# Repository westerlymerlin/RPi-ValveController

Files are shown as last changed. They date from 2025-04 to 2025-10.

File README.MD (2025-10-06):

# Valve Controller

### Valve controller is a python app that can operate 24v valves and is controlled via an HTTP API

`app.py`			    Flask application that manages the API 

----------------------------------------------------

`README.pdf`		software description and details how to setup on a Raspberry Pi

Python module documentation can be found in the folder: [docs](./docs/readme.md)

Change log can be found in the file [changelog.txt](./changelog.txt)

`Valve Control Circuit.fzz`     contains the schematics and PCB layout for use in the Fritzing application https://fritzing.org/

### JSON Commands
 
`{'status', '1'}` Return the status of all valves

`{'valveN', 'open'}` Open valve N

`{'valveN', 'close'}` Close valve N

`{'closeallvalves', 1}` close all valves and pipettes   

&nbsp;   
&nbsp;    
&nbsp;  
&nbsp;   
&nbsp;   
&nbsp;   
--------------

#### Copyright (C) 2025 Gary Twinn

This program is free software: you can redistribute it and/or modify  
it under the terms of the GNU General Public License as published by  
the Free Software Foundation, either version 3 of the License, or  
(at your option) any later version.  

This program is distributed in the hope that it will be useful,  
but WITHOUT ANY WARRANTY; without even the implied warranty of  
MERCHANTABILITY or FITNESS FOR A PARTICULAR PURPOSE. See the  
GNU General Public License for more details.  

You should have received a copy of the GNU General Public License  
along with this program. If not, see <https://www.gnu.org/licenses/>.

Author:  Gary Twinn  
Repository:  [github.com/westerlymerlin](https://github)

-------------

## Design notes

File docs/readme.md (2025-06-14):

# Module Documentation

This document contains the documentation for all the modules in this project.

---

## Contents

[app](./app.md)  
Valve Controller Web Application

A Flask-based web application for monitoring and controlling valves through a REST API.
This module serves as the main entry point and is designed to be run by Gunicorn.

Features:
- Web interface for valve status monitoring
- REST API for programmatic valve control with API key authentication
- System monitoring (CPU temperature, thread listing)
- Log viewing (application logs, Gunicorn logs, system logs)

The application exposes endpoints for valve control, system status, and log viewing.

[app_control](./app_control.md)  
Settings module, reads the settings from a settings.json file. If it does not exist or a new setting
has appeared it will creat from the defaults in the initialise function.

[logmanager](./logmanager.md)  
logmanager, setus up application logging. use the **logger** property to
write to the log.

[valvecontrol](./valvecontrol.md)  
Raspberry Pi Valve Control System

This module provides a comprehensive interface for controlling and monitoring laboratory
valves via Raspberry Pi GPIO pins. It implements safety interlocks to prevent conflicting
valve states, handles system commands, and provides status monitoring capabilities.

Features:
- Individual valve control (open/close) with conflict prevention
- Batch operations (close all valves)
- System control commands (restart)
- Status reporting for monitoring
- Logging of all valve operations and errors

The module initializes GPIO pins, defines valve configurations with their relationships,
and provides functions for valve manipulation through a consistent interface.

Dependencies:
- RPi.GPIO: For hardware control of GPIO pins
- threading.Timer: For delayed execution of commands
- logmanager: For operational logging

---

-------
#### Copyright (C) 2025 Gary Twinn  

This program is free software: you can redistribute it and/or modify
it under the terms of the GNU General Public License as published by
the Free Software Foundation, either version 3 of the License, or
(at your option) any later version.

This program is distributed in the hope that it will be useful,
but WITHOUT ANY WARRANTY; without even the implied warranty of
MERCHANTABILITY or FITNESS FOR A PARTICULAR PURPOSE. See the
GNU General Public License for more details.  
  
You should have received a copy of the GNU General Public License
along with this program. If not, see <https://www.gnu.org/licenses/>.  
  
  ##### Author: Gary Twinn  
  
 -------------

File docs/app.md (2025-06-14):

# None

# app

Valve Controller Web Application

A Flask-based web application for monitoring and controlling valves through a REST API.
This module serves as the main entry point and is designed to be run by Gunicorn.

Features:
- Web interface for valve status monitoring
- REST API for programmatic valve control with API key authentication
- System monitoring (CPU temperature, thread listing)
- Log viewing (application logs, Gunicorn logs, system logs)

The application exposes endpoints for valve control, system status, and log viewing.

## subprocess

## enumerate\_threads

## Flask

## render\_template

## jsonify

## request

## logger

## httpstatus

## valvestatus

## parsecontrol

## settings

## VERSION

#### app

#### read\_log\_from\_file

```python
def read_log_from_file(file_path)
```

Reads and returns the reversed content of a log file.

This function opens the specified file in read mode with UTF-8 encoding, reads its
contents into a list of lines, reverses the order of the lines, and returns the
reversed list.

Args:
    file_path (str): The path to the file to be read.

Returns:
    list: A list of strings representing the lines of the file, in reversed order.

#### read\_cpu\_temperature

```python
def read_cpu_temperature()
```

Reads the CPU temperature from a file specified in the application settings.

This function opens the file path defined in the settings, reads the CPU
temperature data in millidegrees Celsius, converts it to degrees Celsius, and
rounds the resulting value to one decimal place before returning it.

Raises:
    FileNotFoundError: If the file path specified in the settings does not
        exist.
    IOError: If there is an error reading the file.
    ValueError: If the temperature file content cannot be converted to a float.

Returns:
    float: The CPU temperature in degrees Celsius, rounded to one decimal place.

#### threadlister

```python
def threadlister()
```

Generates a list of threads currently running in the application.

This function retrieves all active threads in the process, collecting their
names and native thread IDs, and returns the result as a list. Each thread's
information is represented as a sublist containing the thread's name and ID.

Returns:
    list: A list of sublists where each sublist contains a thread's name
        and native thread ID.

#### index

```python
@app.route('/')
def index()
```

Define a route for the root URL that renders the 'index.html' template with various
context values including CPU temperature, valve states, application version, and
running threads.

Returns
-------
flask.Response
    The HTTP response object containing the rendered HTML template.

#### api

```python
@app.route('/api', methods=['POST'])
def api()
```

Handles API POST requests to execute instructions on a specified item.

This function is a Flask route handling API calls. It checks the headers
of the request for an API key and validates it. If the key is valid, it
processes the request to execute a command on the given item via the
`parsecontrol` function. The response about the item's status is then
returned in JSON format. In case of incorrect or missing API key, or
if the request contains malformed JSON, appropriate HTTP error
responses are returned.

Raises:
    KeyError: If the required 'item' or 'command' fields are missing from
    the request JSON payload, or if the 'Api-Key' header is not
    present or malformed.

Returns:
    Response: On valid API key and request, returns the status
    of the requested command in JSON format along with a
    201 status code.
    str: Returns an error message with a 401 status code
    in cases of unauthorized access or JSON parsing errors.

#### showplogs

```python
@app.route('/pylog')
def showplogs()
```

Route definition for displaying Python logs.

This route handles the '/pylog' URL path and renders a template
that displays the Valve-Control log, including CPU temperature
and the application version.

Returns:
    flask.Response: The rendered HTML template with context data
    including logs, log title, CPU temperature, and version.

#### showgalogs

```python
@app.route('/guaccesslog')
def showgalogs()
```

Handles the display of Gunicorn access logs and CPU temperature.

This function retrieves the current CPU temperature and the Gunicorn access logs,
and then renders the `logs.html` template to display the logs alongside the CPU
temperature.

Returns:
    str: The rendered HTML content for the logs page.

#### showgelogs

```python
@app.route('/guerrorlog')
def showgelogs()
```

Provides the view for displaying the Gunicorn error logs.

This function reads the CPU temperature and Gunicorn error log content from
files and renders them in an HTML template. It serves as the backend handling
for the endpoint `/guerrorlog`.

Returns:
    str: Rendered HTML template displaying the logs and other related
    information.

#### showslogs

```python
@app.route('/syslog')
def showslogs()
```

Handles the '/syslog' route to display system log entries in reverse order along
with CPU temperature.

Creates a Flask route that retrieves the latest system logs, reverses their
order, and renders them to an HTML template. Additionally, it retrieves and
displays the CPU temperature and a version parameter.

Returns:
    str: Rendered HTML page showing system logs, CPU temperature, and a version
    identifier.

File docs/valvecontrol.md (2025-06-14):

# None

# valvecontrol

Raspberry Pi Valve Control System

This module provides a comprehensive interface for controlling and monitoring laboratory
valves via Raspberry Pi GPIO pins. It implements safety interlocks to prevent conflicting
valve states, handles system commands, and provides status monitoring capabilities.

Features:
- Individual valve control (open/close) with conflict prevention
- Batch operations (close all valves)
- System control commands (restart)
- Status reporting for monitoring
- Logging of all valve operations and errors

The module initializes GPIO pins, defines valve configurations with their relationships,
and provides functions for valve manipulation through a consistent interface.

Dependencies:
- RPi.GPIO: For hardware control of GPIO pins
- threading.Timer: For delayed execution of commands
- logmanager: For operational logging

## Timer

## os

## GPIO

## logger

#### channellist

#### valves

#### parsecontrol

```python
def parsecontrol(item, command)
```

Parses and executes control instructions for items such as valves or system commands.

This function handles control commands for items (e.g., valves) by executing
the corresponding actions (opening, closing, restarting, etc.). It utilizes specific
rules to process the commands and takes recovery measures in case of invalid inputs
or errors.

Parameters:
item : str
    Specifies the name of the control item (e.g., 'valve1', 'closeallvalves', 'restart').
command : str
    Provides the command to execute for the given item (e.g., 'open', 'close', 'pi').

Raises:
ValueError
    If the conversion of values such as valve number fails.
IndexError
    If accessing an invalid index during item processing.

#### valveopen

```python
def valveopen(valveid)
```

Opens a valve based on its unique identifier if no conflicting valve is open.

Attempts to open the valve identified by the provided valve ID. Before opening,
it checks whether the valve marked as excluded for the specified valve is already open.
If the excluded valve is open, the operation is aborted, logging a warning.
If no conflict is found, the specified valve is opened, and this action is logged.

Parameters:
    valveid (int): The unique identifier of the valve to be opened.

#### valveclose

```python
def valveclose(valveid)
```

Closes the specified valve based on its ID.

The function identifies the valve with the given ID in the list of valves,
ensures that the valve's GPIO pin is set to a low state, and logs the
operation. This action effectively closes the valve. The provided valve
ID should match an existing valve's ID within the list.

Parameters:
    valveid (int): The ID of the valve to be closed.

#### allclose

```python
def allclose()
```

Close all valves by setting the output of the specified channels to 0.

Summary:
This function outputs a signal of 0 to all channels specified in the
'channellist', effectively closing all valves. It also logs an info
message indicating the operation.

Parameters:
channellist : list
    A list of GPIO channel numbers on which the output will be set to 0.

Returns:
None

#### status

```python
def status(value)
```

Determines the status based on a given value.

This function evaluates the provided integer value and returns a corresponding
status string. Specifically, it checks whether the value equals zero to
determine if the status is 'closed'. Any other value results in a status
of 'open'.

Parameters:
value (int): The value to evaluate for determining the status.

Returns:
str: A string representing the status. Returns 'closed' if the value is
0; otherwise, returns 'open'.

#### valvestatus

```python
def valvestatus()
```

Determines the status of valves based on their GPIO input.

This function iterates through a list of valves, checks each valve's GPIO
input status, and compiles a list of dictionaries containing the valve ID
and its respective status.

Returns:
    list[dict]: A list where each dictionary contains the ID of a valve and
    its corresponding status, based on GPIO input.

#### httpstatus

```python
def httpstatus()
```

Determine and return the status of a list of valves based on their GPIO input.

This function iterates through a list of valve objects, checks each valve's GPIO
input to determine its status and then constructs a list of dictionaries containing
the valve's ID, description, and current status.

Returns:
    list[dict]: A list of dictionaries each containing the valve's `id` (int),
    `description` (str), and its current `status` (bool or other relevant type
    returned by the `status` function).

#### reboot

```python
def reboot()
```

Reboots the local machine.

This function logs a warning message indicating that the system is about to restart
and then executes a system command to initiate a reboot.

Raises:
    This function does not explicitly raise any exceptions, but it depends on the
    behavior of the underlying operating system and might fail in environments
    without sufficient permissions.

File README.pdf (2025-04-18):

# Valve and Laser Controller

Software Functional Requirements

By Gary Twinn

## Contents

Valve and Laser Controller | 1
Contents | 2
List of Figures | 3
List of Tables | 4
Overview | 5
Input Messages | 5
Output Messages | 7
Valve to GPIO assignment | 8
Driver circuits and power supply | 9
Web interface | 11
Interfaces | 12
Valve Cable Specification | 12
Laser TTL Cable specification | Error! Bookmark not defined.
Operating System Installation | 13
Operating system | 13
Software installation | 13
Run Operating System Updates | 13
Install PIP3 for Python 3.x installation | Error! Bookmark not defined.
Install Flask installation | 13
Download Valve Controller Application | Error! Bookmark not defined.
Copy the python files to the Pi | Error! Bookmark not defined.
Nginx installation | 15
Gunicorn for Python 3.x installation | 14

## List of Figures

Figure 4: Laser TTL D Plug Assignment | Error! Bookmark not defined.

## List of Tables

## Overview

The valve and laser control software consists of a python (Python Software Foundation 2023) application to control the 12 valves of the Helium line and a single channel Transistor -Transistor Logic (TTL) output to switch on/off the Laser.

Valve | Description
| 4 He pipette input
| 4 He pipette output
| 3 He pipette output
| 4 He pipette input port 1(not currently used) ion pump gas analyser gallery A laser cell getter buffer tank turbo pump

Table 1: He line valves
The computer that controls the valves is a Raspberry Pi 4B (Raspberry PI Foundation 2020), it uses a 40 way connector to break out the required 12 GPIO pins and connect to the driver boards.

Each valve is controlled by a dedicated GPIO line on the raspberry Pi computer. The valves run on 24V DC and the Pi uses a 3.3V signal, so a driver circuit is required to step up the voltage and current from the Pi.

The computer is controlled via a RESTful API listening on port 80 for a valid json message.

The software contains logic to prevent the input and output valves on a pipette opening at the same time in the case of a mistake in the commands sent to the computer. (valve 1 and valve 2), (valve 3 and valve 4)

To simplify charging and unloading of pipettes a single command was implemented to load and unload each pipette. The pipette command contains a 0.5s delay between one valve closing and one opening.

A single command was also implemented to close all valves and switch off the laser in case of an issue.

## Input Messages

Json messages in the following formats are accepted:

Open a single valve (nn):

{
"item": "valvenn",
"command": "open"
}

Close a single valve (nn): {
"item": "valvenn",
"command": "close"
}

Close all valves:
{
"item": "closeallvalves"
"command": ""}

Get Valve Status: (for all valves and laser) {
"item": "getstatus",
"command": ""
}

## Output Messages

Following any valid command, the following data is returned: (ss = open or closed, xx = on or off )
{
"status": "ss",
"valve": 1
},
{
"status": "ss",
"valve": 2
},
{
"status": "ss",
"valve": 3
},
{
"status": "ss",
"valve": 4
},
{
"status": "ss",
"valve": 5
},
{
"status": "ss",
"valve": 6
},
{
"status": "ss",
"valve": 7
},
{
"status": "ss",
"valve": 8
},
{
"status": "ss",
"valve": 10
},
{
"status": "ss",
"valve": 11
},
{
"status": "ss",
"valve": 12
},
{
"status": "ss",
"valve": 13
}
{
"laser": "0",
"status": "xx"
}

## Valve to GPIO assignment

Valve | Designation | Connector | Designation | Valve
| 3v3 | 1 | 2 | 5v
| GPIO 02 | 3 | 4 | 5v
| GPIO 03 | 5 | 6 | GND
| GPIO 04 | 7 | 8 | GPIO 14
| GND | 9 | 10 | GPIO 15
Valve 2 | GPIO 17 | 11 | 12 | GPIO 18 | Valve 5
Valve 6 | GPIO 27 | 13 | 14 | GND
Valve 10 | GPIO 22 | 15 | 16 | GPIO 23 | Valve 1
| 3v3 | 17 | 18 | GPIO 24 | Valve 8
| GPIO 10 | 19 | 20 | GND
Valve 7 | GPIO 09 | 21 | 22 | GPIO 25
Valve 11 | GPIO 11 | 23 | 24 | GPIO 08
| GND | 25 | 26 | GPIO 07
| GPIO 00 | 27 | 28 | GPIO 01
| GPIO 05 | 29 | 30 | GND
| GPIO 06 | 31 | 32 | GPIO 12 | Ready LED
Valve 3 | GPIO 13 | 33 | 34 | GND
Valve 4 | GPIO 19 | 35 | 36 | GPIO 16
Valve 13 | GPIO 26 | 37 | 38 | GPIO 20
| GND | 39 | 40 | GPIO 21 | Valve 12

Table 2: GPIO to valve assignments
Table 1 shows GPIO channels on a Raspberry Pi 4B, channels in green are available and remain at 0v during the Pi boot up sequence, it is important that no lines are used that could cause the laser to turn on or a valve to open before the software is ready.

Once the boot sequence has completed and the software has started the final command on the initialising function will be to light the “Ready LED” (GPIO12) to give a visual indication the Raspberry PI had booted and is ready to accept commands on the REST api.

## Driver circuits and power supply

The Raspberry Pi 4 uses a 5v power supply provided via a USB-C connector. A 5V power supply rated at 3A will be required. The Raspberry Pi internal voltage and the outputs of the GPIO connectors is 3.3v.

The valves are opened by applying 24V DC to the solenoid, when the power is removed the valves will close against a spring. The assumption is that the maximum number of valves that could be actuated (during a pump-down cycle) would be 10 valves so the supply should be able to supply a minimum of 1.0A continuously. In order to provide this level of current reliably a 24V power supply with a continuous rating of 3.0A will be required.

In order to protect the Raspberry Pi from any voltage spikes that may be generated by the solenoids as the valves close, or a faulty component, an opto-isolator will be required to provide full electrical isolation between the Pi and the driver circuit.

The solenoids on the valves will be driven via Metal Oxide Field Effect Transistors (MOSFET). MOSFETs have a very low forward voltage once switched on and have a high-power capacity (Inchange Semiconductor 2016).

As the valves are operated by inductive solenoids, when the power is removed from the solenoids there is a chance voltage spikes will be induced into the circuit so a Schottky diode will protect the MOSFET and opto-isolator.

Each valve driver board has 4 channels so the valve controller requires 3 driver boards to control the 12 valves (Figure 1).

The driver circuit will need to be housed in an enclosure that has external connectors for the mains supply, ethernet cable and connectors for the 12 valve cables. It must have ventilation holes to prevent the Raspberry Pis, power supplies or driver MOS-FET transistors overheating. Indicator lights should show the status of the 5v PSU for the Raspberry Pi, the 24V valve PSU and the software ready light.

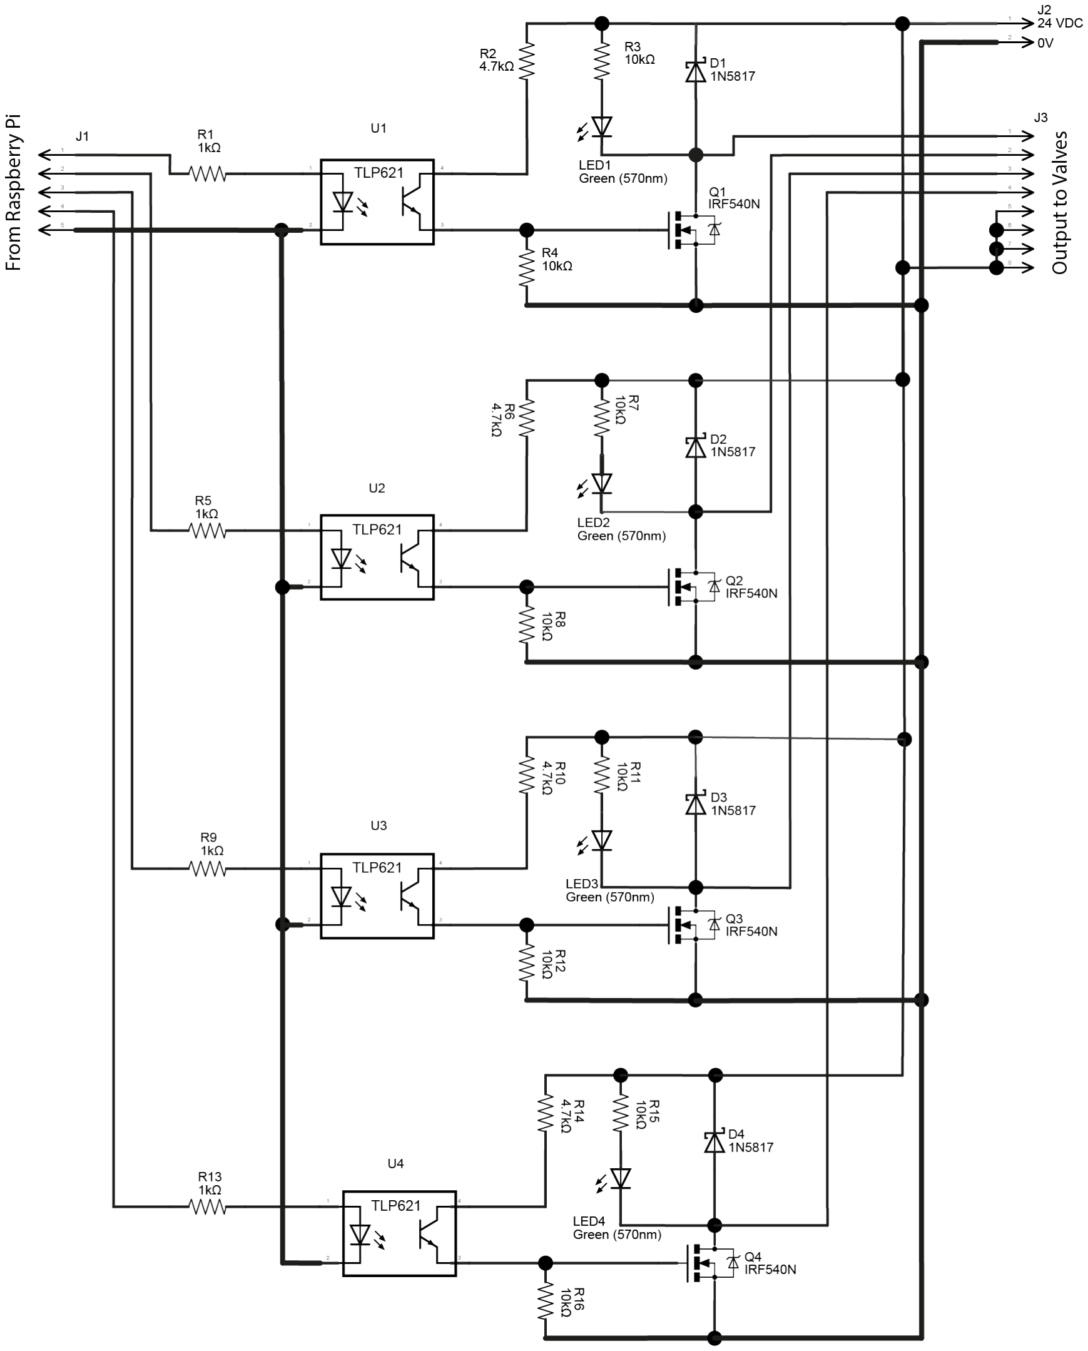
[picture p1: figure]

Figure 1: Schematic for a valve driver board

## Web interface

As well as accessing the status of the valves via the RESTful API a read-only web interface that can be accessed directly from a browser is will be available to view the valve status, application and web server logs.

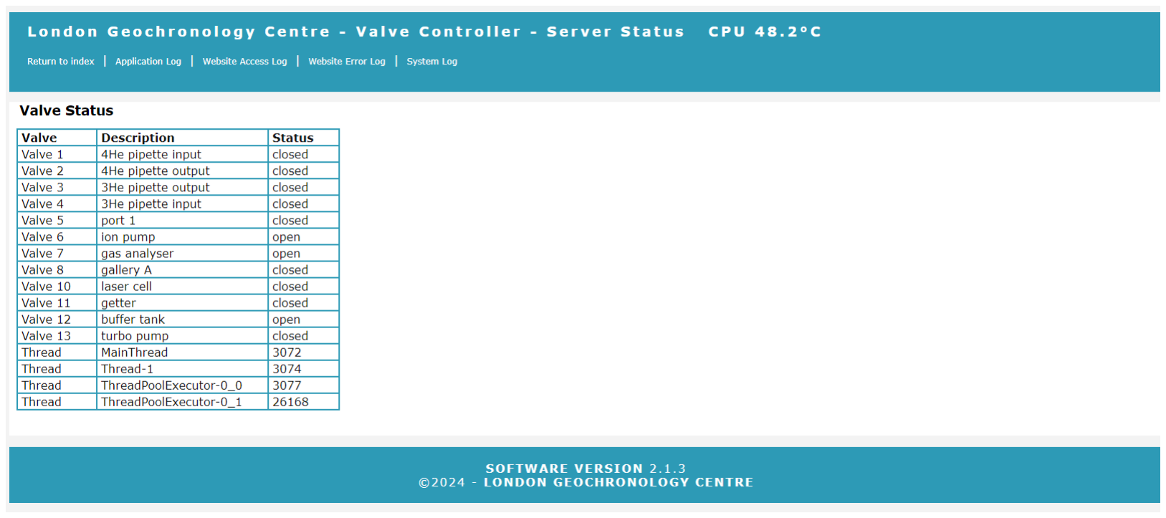
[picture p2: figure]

Figure 2: Web status page

## Interfaces

## Valve Cable Specification

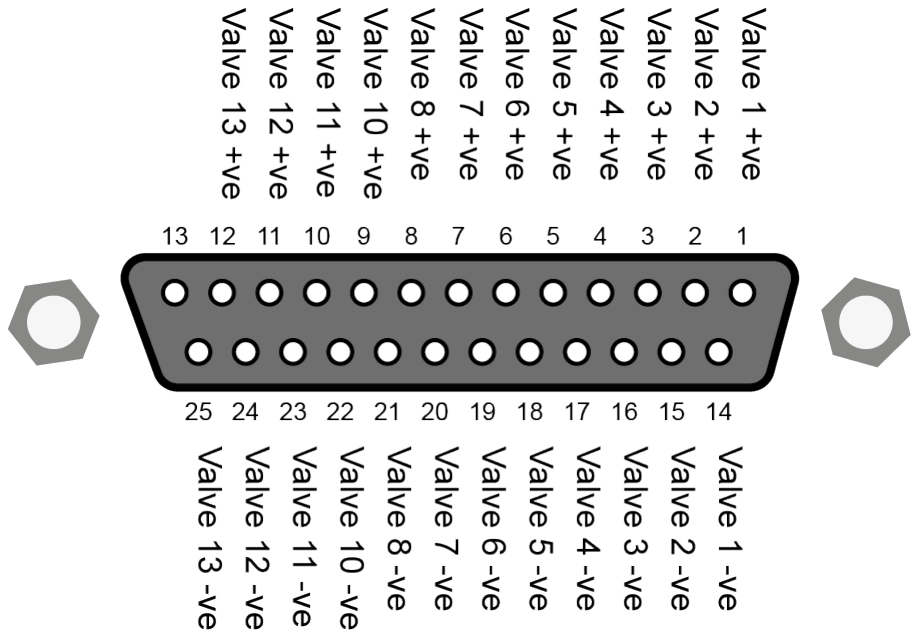
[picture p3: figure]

Figure 3: Valve controller D plug assignments

A 25 pin D plug connected to 12 individual cables, each terminated with an SMC 24v latching power plug.

## Operating System Installation

## Operating system

Use BalenaEtcher to install the latest version of the bookworm-lite 64bit operating system onto a 32Gb MicroMMC card.

Run the sudo raspi-config command to:
♦ enable ssh
♦ disable Serial
♦ disable 1²

C bus
♦ set the password on the pi user account to something other than “raspberry” ♦ change the GPU memory to 16Gb

## Software installation

## Run Operating System Updates

Run sudo apt update
Run sudo apt upgrade

## Install git and gh

Run sudo apt install git
Run sudo apt install gh
Run gh auth login
- What account do you want to log into? GitHub.com
- What is your preferred protocol for Git operations? HTTPS
- Authenticate Git with your GitHub credentials? (Y/n) y
- How would you like to authenticate GitHub CLI? Paste an authentication token

## Configure git and download the valve controller code

Create a GitHub folder
Run mkdir github
Run cd github

Clone the repo
Run git clone https://github.com/westerlymerlin/UCL-RPi-ValveController.git

Copy the files to the home folder
Run cp -r ~/github/UCL-RPi-ValveController/* ~/

Set the execute flag on the scripts
Run chmod 755 ~/bin/*

Copy the Raspberry pi config files to the etc folder Run sudo cp -r ~/raspberry-pi/etc/* /etc

Reboot the Raspberry pi
Run sudo reboot

After the reboot a warning banner will appear at ssh logon.

## Create a python venv

Run python3 -m venv .venv

## Change to the venv

Run source activate

## Install the Flask libraries

Run pip install gunicorn flask

## Gunicorn for Python service

Run sudo systemctl enable gunicorn Run sudo systemctl start gunicorn

## Nginx installation

Run sudo apt install nginx

Change directory to /etc/nginx/sites-enabled/
Run sudo rm default
Run sudo ln -s /etc/nginx/sites-available/icpmsdata

Reboot the Raspberry pi
Run sudo reboot

If flask is installed, the python files are in the /home/pi directory, gunicorn3 is installed and configured and nginx is installed and configured the web service should be running and the site will be accessible on http://ip address of the server

References

Inchange Semiconductor (2016) IRF540N. Available online: http://www.iscsemi.com [Accessed.
Python Software Foundation (2023) Python 3 Programming Language. Online. Available online: https://www.python.org [Accessed March 2023].
Raspberry PI Foundation (2020) Raspberry PI Model 4B Reference. Available online: https://www.raspberrypi.org/products/raspberry-pi-4-model-b/ [Accessed July 2020].

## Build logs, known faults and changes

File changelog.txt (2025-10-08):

Version     Description
2.1.6       Added constraint so valves 10 and 5 are mutually exclusive
2.1.5       Removed constraint on Valve 5 being closed
2.1.4       Removed references to pipette control
2.1.3       BUG FIX system log viewer needs full path to work
2.1.2       Force all valves to close on app restart
2.1.1       Added thread info to the home screen
2.1.0       Change to venv python
2.0.9       Bugfix API Key not working
2.0.8       Bugfix API Key not working
2.0.7       Added API Key in settings
2.0.6       Updates following static code analysis
2.0.5       Updates following static code analysis
2.0.3       Configuration changes
2.0.2       Update to web interface - colour codes on log pages
2.0.1       Update to web interface - added cpu temperature to status page
2.0.0       Update to web interface
1.2.0       Added api command to restart pi
1.1.4       Added software version to status page

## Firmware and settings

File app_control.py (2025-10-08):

"""
Settings module, reads the settings from a settings.json file. If it does not exist or a new setting
has appeared it will creat from the defaults in the initialise function.
"""
import random
import json
from datetime import datetime

VERSION = '2.1.6'

def initialise():
    """Setup the settings structure with default values"""
    isettings = {'LastSave': '01/01/2000 00:00:01',
                 'app-name': 'UCL Helium Line Valve Controller',
                 'api-key': 'change-me',
                 'logfilepath': './logs/valvecontroller.log',
                 'logappname': 'Valve-Controller-Py',
                 'loglevel': 'INFO',
                 'gunicornpath': './logs/',
                 'cputemp': '/sys/class/thermal/thermal_zone0/temp'}
    return isettings


def generate_api_key(key_len):
    """generate a new api key"""
    allowed_characters = "ABCDEFGHJKLMNPQRSTUVWXYZ-+~abcdefghijkmnopqrstuvwxyz123456789"
    return ''.join(random.choice(allowed_characters) for _ in range(key_len))


def writesettings():
    """Write settings to json file"""
    settings['LastSave'] = datetime.now().strftime('%d/%m/%Y %H:%M:%S')
    with open('settings.json', 'w', encoding='utf-8') as outfile:
        json.dump(settings, outfile, indent=4, sort_keys=True)


def readsettings():
    """Read the json file"""
    try:
        with open('settings.json', 'r', encoding='utf-8') as json_file:
            jsettings = json.load(json_file)
            return jsettings
    except FileNotFoundError:
        print('File not found')
        return {}


def loadsettings():
    """Replace the default settings with thsoe from the json files"""
    global settings
    settingschanged = False
    fsettings = readsettings()
    for item in settings.keys():
        try:
            settings[item] = fsettings[item]
        except KeyError:
            print('settings[%s] Not found in json file using default' % item)
            settingschanged = True
    if settings['api-key'] == 'change-me':
        settings['api-key'] = generate_api_key(30)
        settingschanged = True
    if settingschanged:
        writesettings()


settings = initialise()
loadsettings()

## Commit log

2022-12-17 Documentation Update
    [Valve Control Circuit.fzz]
2023-12-27 2.0.0 Update to web interface
    [Valve Control Circuit.fzz]
2023-12-28 2.0.1 Update to web interface - added cpu temperature to status page
2024-02-26 2.0.8 Bugfix API Key not working
    [app.py, settings.py]
2024-02-26 2.0.9 Bugfix API Key not working
    [app.py, settings.py]
2024-08-23 2.1.1 Added thread info to the home screen
2024-12-30 2.1.2
    Update valve initialization to ensure closure on restart
    Extended the channellist and adjusted GPIO setup to initialize all valves in a closed state when the application restarts.
2025-01-13 2.1.3 BUG FIX system log viewer needs full path to work
    [app.py, app_control.py]
2025-02-15 2.1.4 Removed references to pipette control
2025-10-06 2.1.5 Removed constrain on Valve 5 being closed
2025-10-08 2.1.6 Added constraint so valves 10 and 5 are mutually exclusive
